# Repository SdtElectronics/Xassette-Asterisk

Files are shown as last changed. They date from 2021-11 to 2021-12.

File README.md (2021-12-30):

# Xassette-Asterisk
Evaluation board for AllWinner's RISC-V 64 SoC F133/D1s

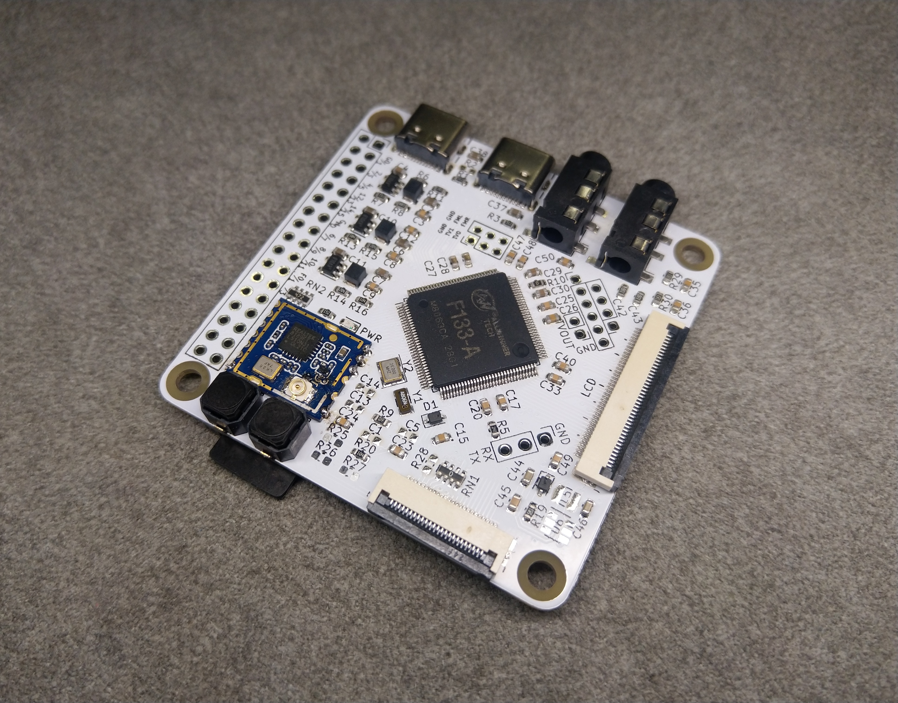
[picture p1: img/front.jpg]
front


## Highlights
* Breaks out all IOs, involving analog peripherals, in a compact 56*56mm 2-layer board
* Comes with standard interfaces including USB, micro SD, LCD, Line-in and headphone
* Optimized components arrangement for soldering on a hot plate

## About the Chip
D1s/F133: RISC-V 64 single core @1.008G with in package 64MB DDR2

## Guides
[Quick Start](docs/quickStart.md)

[Troubleshooting](docs/troubleshooting.md)

[Wi-Fi](docs/WiFi.md)

## Pin Out
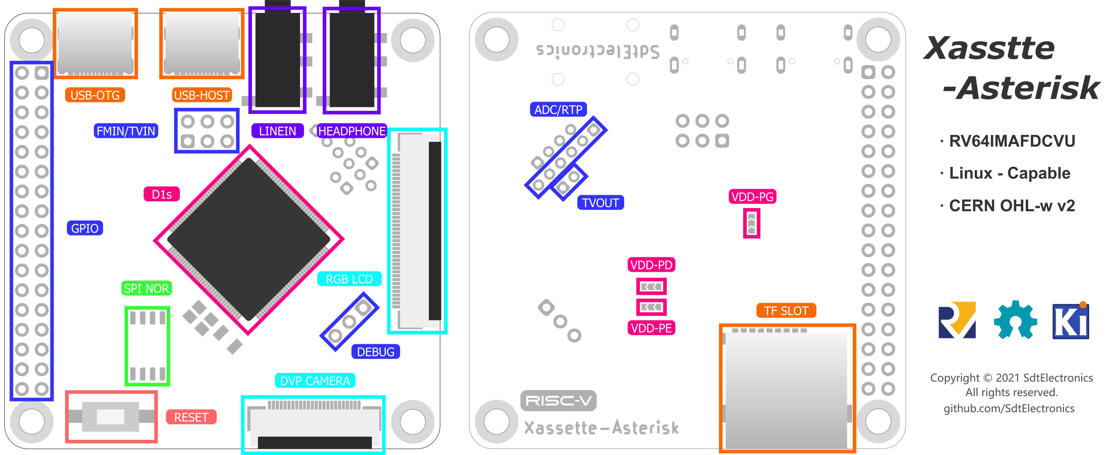
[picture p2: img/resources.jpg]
resources


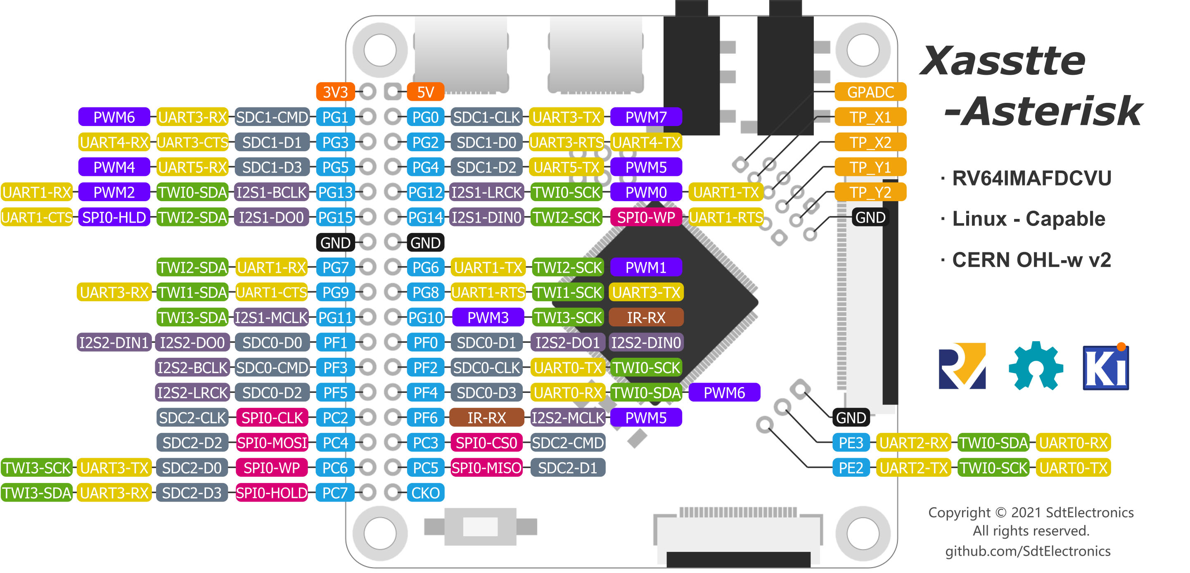
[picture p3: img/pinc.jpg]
pinout


Pins for LCD and DVP camera can also be used as IOs. See schematic below for detailed pin assignment.

## Schematic & BOM
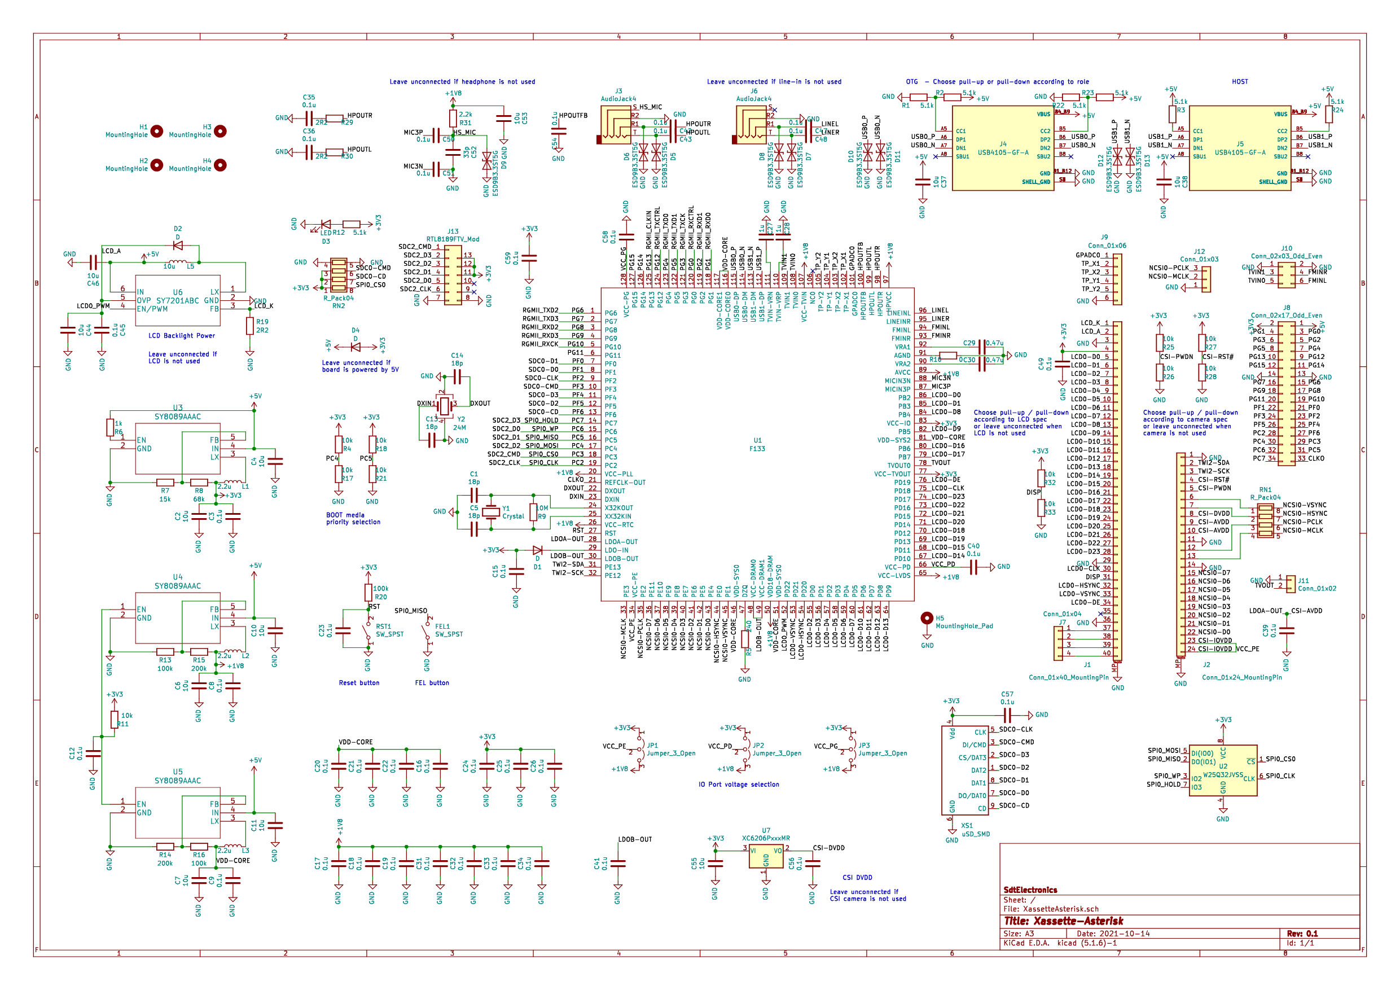
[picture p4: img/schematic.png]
schematic


The schematic in KiCAD format is available under [hw](hw/). BOM in csv format is at [docs/BOM.csv](docs/BOM.csv), and kitspace provides an [online BOM](https://kitspace.org/interactive_bom/?github.com/SdtElectronics/Xassette-Asterisk). Do note that many components are optional (required by some specific peripherals)!

## Notes
* Leave all BOOT selection resistors unconnected if only one BOOT media is present
* Choose load capacitors according to specs of crystals
* When board is to be powered by 3.3V, connect to the power via the 3.3V pin of the pinheader, and `D4` should be soldered. Note USB host will not work properly in this condition due to the absence of 5V power.

## Accessories
### IO Expansion Board
To make use of IOs in the LCD port easier, [this expansion board](hw/auxiliary/Brk40p) converts all nets from FPC to 2.54mm pin headers with labeled IO indices. For 24pin DVP port, there is also an [expansion board](https://github.com/SdtElectronics/Biscuits/tree/master/24P_FPC_FFC_Breakout) but with no labels.

## CHANGELOG
### hw-v0.2 
* Added WiFi Module on `sdc2`, sharing pins with SPI Flash
* Added FEL button
* Added ESD protection on USB and audio jacks
* Changed pin headers of TVIN and FMIN (`J10`) to 2x3 2.00mm to optimize routing of USB

### fw-v0.2
* Enabled pins of `sdc2` for SDIO
* Packed driver for RTL8189ftv WiFi module

**NOTE**: hw-v0.1 board can **NOT** boot fw-v0.2 firmware. Use fw-v0.1 instead.

### hw-v0.3
* Fix pull-up/down resistors for USB-PD role detection
* Align voltage of `VDDIO` in DVP interface with `VCC-PE`

## FAQ
> Are you going to sell some manufactured boards?

No. I have no time and resource to batch manufacture this board. Some commercial boards should come in a couple of months (not from me).

> Where to buy some D1s chips?

There are several suppliers providing samples on taobao.

> Where to find the BSP? Can I build the firmware myself?

The tina BSP for D1s is opened to public and you can download it via [the mirror at linux-sunxi.org](https://dl.linux-sunxi.org/D1/SDK/). There is also [a good guide on linux-sunxi.org](https://linux-sunxi.org/D1_SDK_Howto) covering the building and trouble shooting.

> More information? Like what can this board do now?

The progress of this project is logged at [this Hackaday page](https://hackaday.io/project/182389-the-cheapest-risc-v-64-computer-by-now), and this repository will contain the source and documentation of this board only. Currently this board can boot up the tina Linux system (an OpenWRT fork by Allwinner) and populate a shell prompt via the serial, drive a parallel RGB display, play sounds via the headphone socket, and record audio from MIC. More functionalities will be tested in the future.

**Additional Words**

This project has gained unexpected popularity since the announcement. Thanks for all the interest! However, I am merely an enthusiast with limited time can be put on this, so I am sorry to disappoint who want to buy one. It is perfectly Okay if someone want to put this into production, as long as my work is acknowledged and the Licence is followed (better if you could contact me in advance). 

D1s is an awesome chip with many features to be exploited. Designing a PCB is not hard as the arrangement of pins is quite thoughtful. The crucial part is correct values of some key components, and they were all marked in the schematic. A symbol of D1s with annotated pins is also included in this repository, so this should also be a good start point for your own design.

## External Links
[Page on Hackaday ](https://hackaday.io/project/182389-the-cheapest-risc-v-64-computer-by-now)

[Post about batch manufacturing by cnx-software](https://www.cnx-software.com/2021/12/24/manufacturing-xassette-asterisk-open-source-hardware-board/)

[WiKi on Linux-sunxi.org](https://linux-sunxi.org/Xassette_Asterisk)

## Licence
This project is available under the [CERN OHL-w v2](https://ohwr.org/project/cernohl/wikis/Documents/CERN-OHL-version-2) licence.

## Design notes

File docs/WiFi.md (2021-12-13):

# WiFi
Xassette-Asterisk supports SDIO Wi-Fi module since hw v0.2. The module is connected to SoC via `sdc2` which shares pins with SPI flash, thus the flash won't be available when Wi-Fi module is in use.

## Module Selection
Due to the limited area of PCB, there is no onboard antenna for the module. Thus the module must have an IPEX socket to connect external antenna. RTL8189ftv is the module used to test the Wi-Fi functionality, and it will be the example for the following sections.

## Kernel Configuration
To enable the `sdc2` interface as SDIO card controller, the board device tree must configure `sdc2` as below:
```c
&sdc2 {
        non-removable;
        bus-width = <4>;
        no-mmc;
        no-sd;
        cap-sd-highspeed;
        cap-sdio-irq;
        keep-power-in-suspend;
        ignore-pm-notify;
        max-frequency = <150000000>;
        ctl-spec-caps = <0x308>;
        status = "okay";
};
```
and the `no-sdio` property must be removed from the `sdc2` node in chip's device tree (sun20iw1p1.dtsi).

After this, the SD card will probably be probed as `mmcblk1` (originally `mmcblk0`) and causes the VFS fail to mount the root partition. Changing the path of root (in bootargs) in u-boot solves the problem.

The firmware image with configuration supports Wi-Fi is available in [release](https://github.com/SdtElectronics/Xassette-Asterisk/releases/tag/fw-v0.2). It can be flashed to the card following [Quick Start](docs/quickStart.md).

## Driver
Driver for RTL8189ftv can be compiled following [sunxi WiKi](https://linux-sunxi.org/Wifi#RTL8189FTV). This driver is included in the firmware mentioned above. Load it with 
```
insmod 8189fs
```
and the module is ready to work.

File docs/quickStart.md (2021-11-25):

# Quick Start
## Burn Tina Firmware
Get the firmware in [releases](https://github.com/SdtElectronics/Xassette-Asterisk/releases/tag/fw-v0.1-beta). Extract the tarball and you will get a card image. It could be burned to a SD using `dd` command:
```bash
dd if=fw.bin of=${card} bs=512
```
where ${card} is the path to the device file (under `/dev/`) to your card.

## Access The Shell via ADB
The firmware is preconfigured so that it works as an ADB USB gadget after booted up. Connect the board via the otg port and if your computer has installed ADB and corresponding drivers, the shell should be prompted after entering
```bash
adb shell
```

## Debugging via Serial
The serial prints boot log and kernel messages in addition to the shell prompt. The default debug serial is `UART0` at `PE3` and `PE2`. It can be easily connected with a pinheader at the bottom right of the board.

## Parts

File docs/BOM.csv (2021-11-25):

Comment | Designator | Footprint | Pins | Quantity
1u | C28,C27, | C_0603_1608Metric | 2 | 2
0.47u | C29,C30, | C_0603_1608Metric | 2 | 2
10u | C44,C38,C37,C4,C2,C6,C7,C10,C11, | C_0603_1608Metric | 2 | 9
0.1u | C50,C49,C48,C47,C46,C45,C43,C42,C40,C36,C35,C33,C17,C26,C25,C24,C1,C5,C23,C20,C3,C12,C9,C8,C15, | C_0603_1608Metric | 2 | 27
1N5819 | D1,D2, | D_SOD-323 | 2 | 2
LED | D3, | LED_0603_1608Metric | 2 | 1
Conn_01x40_MountingPin | J1, | TE_4-1734839-0_1x40-1MP_P0.5mm_Horizontal | 42 | 1
Conn_01x24_MountingPin | J2, | TE_2-1734839-4_1x24-1MP_P0.5mm_Horizontal | 26 | 1
2.2u | L2,L3,L1, | L_Wuerth_MAPI-2510 | 2 | 3
10u | L5, | L_Wuerth_MAPI-2510 | 2 | 1
0 | R10, | R_0603_1608Metric | 2 | 1
100k | R13,R11,R12,R16, | R_0603_1608Metric | 2 | 4
200k | R15,R14, | R_0603_1608Metric | 2 | 2
1.5k | R24,R3,R1, | R_0603_1608Metric | 2 | 4
2R2 | R30,R29,R19, | R_0603_1608Metric | 2 | 3
10k | R34,R23,R22, | R_0603_1608Metric | 2 | 11
240 | R5, | R_0603_1608Metric | 2 | 1
15k | R7, | R_0603_1608Metric | 2 | 1
68k | R8, | R_0603_1608Metric | 2 | 1
1k | R6,R20, | R_0603_1608Metric | 2 | 3
0 | RN1, | R_Array_Convex_4x0603 | 8 | 1
SW_SPST | RST, | SW_SPST_FSMSM | 2 | 1
F133 | U1, | LQFP-128_14x14mm_P0.4mm | 128 | 1
W25Q32JVSS | U2, | SOIC-8_5.23x5.23mm_P1.27mm | 8 | 1
SY8089AAAC | U4,U3,U5, | SOT-23-5 | 5 | 3
SY7201ABC | U6, | SOT-23-6 | 6 | 1
32.768k | Y1, | Crystal_SMD_3215-2Pin_3.2x1.5mm | 2 | 1
24M | Y2, | Crystal_SMD_3225-4Pin_3.2x2.5mm | 4 | 1
33p | C52, | C_0603_1608Metric | 2 | 1
10u | C53, | C_0603_1608Metric | 2 | 2
0.1u | C58,C57,C54,C51,C41,C39,C34,C32,C31,C19,C18,C16,C21,C22, | C_0603_1608Metric | 2 | 15
2.2k | R31, | R_0603_1608Metric | 2 | 1
10k | R32, | R_0603_1608Metric | 2 | 2
Through Hole Items
Conn_02x03_Odd_Even | J10, | PinHeader_2x03_P2.54mm_Vertical | 6 | 1
Conn_01x02 | J11, | PinHeader_1x02_P2.00mm_Vertical | 2 | 1
Conn_01x03 | J12, | PinHeader_1x03_P2.54mm_Vertical | 3 | 1
PJ320D | J3,J6, | Jack_3.5mm_PJ320D_Horizontal | 6 | 2
USB4105-GF-A | J5,J4, | GCT_USB4105-GF-A | 18 | 2
Conn_01x04 | J7, | PinSocket_1x04_P2.00mm_Vertical | 4 | 1
Conn_02x17_Odd_Even | J8, | PinSocket_2x17_P2.54mm_Vertical | 34 | 1
Conn_01x06 | J9, | PinHeader_1x06_P2.00mm_Vertical | 6 | 1
uSD_SMD | XS1, | Conn_uSDcard | 15 | 1

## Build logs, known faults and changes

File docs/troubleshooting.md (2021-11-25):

# Troubleshooting

## General
Check voltages of each group of power. The typical voltages for power nets are:
- `3V3`: 3.3V
- `1V8`: 1.8V
- `VDD-CORE`: 0.9V
- `LDOB-OUT`: 1.2-1.3V in FEL mode, 1.8V in normal operation

Check whether there are bad electrical connections.

Check whether separate nets are accidently connected.

## Nothing Is Printed to Serial
Check whether TX and RX signals are matched. Try interchanging them. Remove the boot media and connect the board to a computer via the otg port. If a new device is detected by the computer, it means the chip worked properly and you should check the boot media. Otherwise use an oscilloscope to check whether the crystal is oscillating. If not, check the power, and in worst cases the chip is probably dead.

## System Frequently Hangs or Reboot
Use a better power supply. Remove the load capacitors of 24M crystal (`C13`, `C14`). If the problem is eliminated it indicates the value of load capacitors was too large.

## MMC Errors or Reboot after Mounting New Partion
Check the soldering of the card slot. Use a better card as bad blocks can cause failure.

## LCD Is Not Working
If the backlight is not up, check the boost circuit. Otherwise check the level of `DISP` signal. It should be pulled high for most panels i.e. `R32` should be soldered.

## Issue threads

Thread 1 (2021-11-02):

Any plans for manufacturing?

VedantParanjape, 2021-11-02:
I and few of us would like to do a group buy, do you have a manufacturing plan or any pre made boards with you ?

We are discussing about it here, please join in if possible: https://discord.gg/g2QrdxpZ

cnxsoft, 2021-11-10:
I'm trying to get NextPCB to manufacture 10 fully assembled samples.
They have some questions about specific components, notably where to purchase components, and ask the exact part number for others.
[T-9pcs-BOM(1)-Component question confirm.xlsx](https://github.com/SdtElectronics/Xassette-Asterisk/files/7512594/T-9pcs-BOM.1.-Component.question.confirm.xlsx)

Could you help? Thanks in advance.

SdtElectronics, 2021-11-11:
> I'm trying to get NextPCB to manufacture 10 fully assembled samples. They have some questions about specific components, notably where to purchase components, and ask the exact part number for others. [T-9pcs-BOM(1)-Component question confirm.xlsx](https://github.com/SdtElectronics/Xassette-Asterisk/files/7512594/T-9pcs-BOM.1.-Component.question.confirm.xlsx)
>
> Could you help? Thanks in advance.

@cnxsoft
I have mentioned in the [README](https://github.com/SdtElectronics/Xassette-Asterisk/blob/master/README.md#schematic--bom) that quite a lot of components are optional. I won't recommend soldering them on a prototype, e.g. the nor flash and DVP camera related components (R25-28, C55, C56, C39), as they depend on the application (nor flash for example, you typically want a 64Mbit w25q64 for a minimal useful Linux image, but a 128Mbit w25q128 gives more space for more complex applications).  And note that some components **should NOT** be soldered together since they are mutual exclusive as Boolean switchs (e.g. R4, R18, R17, R21).

For through hole components, mainly pin headers here, I would suggest don't bother leaving them to the manufacturer, as some of them are not needed (for a prototype), and they can be hand soldered easily if you want them.

I have corrected some items in the BOM in this attachment and added some comments. However, problem can still occur as it is not me who contact the manufacturer directly. You may want to show me the rendered visual of SMT board from the manufacturer for further verification.
[T-9pcs-BOM.1.-Component.revised.xlsx](https://github.com/SdtElectronics/Xassette-Asterisk/files/7519220/T-9pcs-BOM.1.-Component.revised.xlsx)

VedantParanjape, 2021-11-20:
> I'm trying to get NextPCB to manufacture 10 fully assembled samples. They have some questions about specific components, notably where to purchase components, and ask the exact part number for others. [T-9pcs-BOM(1)-Component question confirm.xlsx](https://github.com/SdtElectronics/Xassette-Asterisk/files/7512594/T-9pcs-BOM.1.-Component.question.confirm.xlsx)
>
> Could you help? Thanks in advance.

Hey, if you have some leftovers, I'd be happy to buy. Do let me know.

cnxsoft, 2021-11-20:
@VedantParanjape NextPCB will be manufacturing and assembling the boards next week. Maybe I'll get them in two weeks. I'm not sure I'll be able to bring them up though. We'll see.

dwillmore, 2021-11-20:
Good work, cnxsoft, I look forward to your article on them.

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

cnxsoft, 2021-11-22:
@SdtElectronics Sorry to bother you again. The Gerber files are ready but the manufacturer has some questions.

> Our engineer has made the Working gerber for your this order, also with PDF format, please kindly check and see if everything is ok?
>
> Also please check the picture 1, for the position by arrow indicated, it can not be made as solder mask bridge, so our engineer suggest that help you connect the pads together(whole opening), is ok for you?(check the Working gerber)

I don't see any obvious issues in the Gerber, and I don't understand the picture 1 question. If you could comment that would be good. The files are attached below. Thank you.

[nextpcb-gerber.zip](https://github.com/SdtElectronics/Xassette-Asterisk/files/7580142/nextpcb-gerber.zip)

SdtElectronics, 2021-11-22:
@cnxsoft
I assume gaps between pads at some positions are too small to make solder mask upon. As long as the manufacturer will take care of the soldering that would not be a problem, otherwise the absence of solder mask may cause difficulty to soldering (by hand).

cnxsoft, 2021-12-10:
They've manufactured the first sample. See photos.

[T-E41684AST1，GE14895-Sample board photos.zip](https://github.com/SdtElectronics/Xassette-Asterisk/files/7690936/T-E41684AST1.GE14895-Sample.board.photos.zip)

They are asking for feedback. It looks OK except they have not soldered all capacitors yet. What's strange is that they had to solder some of the components at an angle (First photos with red circles), but will fix it later. I don't see this problem on your board, was it an issue?

Their comment:
"In addition, the parts circled by red line, the pads are a little smaller, they may be pulled off in Reflow soldering process, we will help you repair them manually before shipment, but also please improve your this design in future."

SdtElectronics, 2021-12-11:
@cnxsoft
I did find some issues from the pics you uploaded. `R21`, `R18` and `R17`, `R14` are jumpers for boot media selection and they must **NOT** be soldered simultaneously. I have mentioned this in notes of README, as well as the commented BOM list. Should a card was used as the only boot media, all these 4 resistors can be removed. Same reason for `R33` and `R32`. They are jumpers and only one of them should be soldered (`R32` for most LCD panels).

About the skew components (3 inductors in your pics), I have also experienced this when soldering by hot plate (they were right, melted solder paste pulled components off) and I have to adjust them manually. This would not be a problem as long as two pads of the inductor are not shorted.

Closed 2021-11-02.

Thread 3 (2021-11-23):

Firmware image

suarezvictor, 2021-11-23:
Hi, I've got some of the chips and I plan to implement your board or a similar one.
Where to get the firmware images? Are them open source, at least partially?

SdtElectronics, 2021-11-24:
**TL;DR**
I will upload the full image of a bootable SD so it can be `dd`ed to the card directly, hopefully in a few days.

The tina SDK for D1 is open source and it can be get and built following [this instruction](https://d1.docs.aw-ol.com/study/study_4compile/). D1s and D1 has little difference on DRAM so the source should be patched according to [this post](https://bbs.aw-ol.com/topic/384/%E7%AE%80%E5%8D%95%E4%BF%AE%E6%94%B9-%E5%93%AA%E5%90%92d1-tina-sdk-%E7%9A%84-sys_config-fex-%E5%92%8C-board-dts-%E8%AE%A9d1s%E5%85%88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).  All these are in Chinese. You will probably encounter some error during build, and solutions on [aw-dl forum](https://bbs.aw-ol.com/) are in Chinese as well. After a successful compilation, the firmware still has little problem and I have to tune some configuration. I considered writing an instruction for building firmware manually but as you can see that would be very complicated. Thus for anyone who want to build manually, I would suggest you to wait for the mainline support. Before that you can use my image, which will be uploaded  soon. Currently I am working on some final testing.

suarezvictor, 2021-11-24:
Well this is a good start, thanks!
Mainlining could get a unknown amount of time, it seems using your instructions and image would be better. Hopefully you can share such instructions so developers like me can help on tweaking and improving it.

SdtElectronics, 2021-11-25:
The firmware is uploaded and it can be flashed following [Quick Start](https://github.com/SdtElectronics/Xassette-Asterisk/blob/master/docs/quickStart.md).

suarezvictor, 2021-11-25:
This is much appreciated, what a nice project!

Closed 2021-11-25.

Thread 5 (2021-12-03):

My board doesn't boot

foxnux, 2021-12-03:
Thank you for sharing your great work.
I made my F133-A board based on your schematics but it doesn't boot.
There is no serial console data from the UART TX pin (PE2). I set 115200N81 on minicom.
I flashed your prebuilt test image on a micro SD card for my hardware bring up.

I checked power rails and 24Mhz/32.768Khz oscillators work fine.
3.3V: 3.328V
1.8V: 1.813V
Core: 0.908V
LDO_B: 1.379V (!)

When I connected the USB Port 0 to my Linux PC, I could see "ID 1f3a:efe8" from lsusb output.
It seemed that the FEL mode worked at least.

I've checked the SD interface CLK and CMD lines with an oscilloscope. But they were always low (zero volt).
I think BROM didn't try fetching any boot data from the SD card.
I didn't connect any resistors to the boot mode select pins (MOSI/MISO).

Can you please tell me what I am missing?

Thanks in advance,

SdtElectronics, 2021-12-03:
It is probably normal if LDO_B is at 1.3V in FEL mode. There should be no output from the serial in FEL mode and I see no problem from the rest of your description. Have you soldered the jumping wires for voltage selection? Have you tried with another card? You can also try solder the card slot again to ensure it is connected properly.

foxnux, 2021-12-06:
Thank you for the valuable feedback.
I've checked VCC-PD, VCC-PE, VCC-PG and VCC-IO pins. All of them shows stable 3.32Volt
I tried a couple of different micro SD cards. There is no signal toggling on the SD card CLK signal yet. :(
I will check my SD card schematics more carefully.

foxnux, 2021-12-06:
Really appreciate your insight.
After replacing the SD card slot with a different one, I could see the following boot message from the serial console finally. :)

`[217]HELLO! BOOT0 is starting!
[220]BOOT0 commit : 27369ab
[223]set pll start
[225]periph0 has been enabled
[228]set pll end
[229][pmu]: bus read error
[232]board init ok
[234]ZQ value = 0x31***********
[237]get_pmu_exist() = -1
[239]ddr_efuse_type: 0xa
[242][AUTO DEBUG] single rank and full DQ!
[246]ddr_efuse_type: 0xa
[249][AUTO DEBUG] rank 0 row = 13
[252][AUTO DEBUG] rank 0 bank = 4
[255][AUTO DEBUG] rank 0 page size = 2 KB
[259]DRAM BOOT DRIVE INFO: V0.24
[262]DRAM CLK = 528 MHz
[264]DRAM Type = 2 (2:DDR2,3:DDR3)
[268]DRAMC read ODT  off.
[270]DRAM ODT off.
[272]ddr_efuse_type: 0xa
[275]DRAM SIZE =64 M
[278]DRAM simple test OK.
[281]dram size =64
[283]card no is 0
[284]sdcard 0 line count 4
[287][mmc]: mmc driver ver 2021-04-2 16:45
[296][mmc]: Wrong media type 0x0
[299][mmc]: ***Try SD card 0***
[312][mmc]: HSSDR52/SDR25 4 bit
[315][mmc]: 50000000 Hz
[317][mmc]: 60906 MB
[319][mmc]: ***SD/MMC 0 init OK!!!***
[366]Loading boot-pkg Succeed(index=0).
[370]Entry_name        = opensbi
[373]Entry_name        = u-boot
[377]Entry_name        = dtb
[380]mmc not para
[381]Jump to second Boot.

OpenSBI v0.6
   ____                    _____ ____ _____
  / __ \                  / ____|  _ \_   _|
 | |  | |_ __   ___ _ __ | (___ | |_) || |
 | |  | | '_ \ / _ \ '_ \ \___ \|  _ < | |
 | |__| | |_) |  __/ | | |____) | |_) || |_
  \____/| .__/ \___|_| |_|_____/|____/_____|
        | |
        |_|

Platform Name          : T-HEAD Xuantie Platform
Platform HART Features : RV64ACDFIMSUVX
Platform Max HARTs     : 1
Current Hart           : 0
Firmware Base          : 0x40000400
Firmware Size          : 75 KB
Runtime SBI Version    : 0.2

MIDELEG : 0x0000000000000222
MEDELEG : 0x000000000000b1ff
PMP0    : 0x0000000040000000-0x000000004001ffff (A)
PMP1    : 0x0000000040000000-0x000000007fffffff (A,R,W,X)
PMP2    : 0x0000000080000000-0x00000000bfffffff (A,R,W,X)
PMP3    : 0x0000000000020000-0x0000000000027fff (A,�

U-Boot 2018.05-g0a88ac9 (Apr 30 2021 - 11:23:28 +0000) Allwinner Technology

[00.464]DRAM:  64 MiB
[00.466]Relocation Offset is: 01ef0000
[00.471]secure enable bit: 0
[00.473]CPU=1008 MHz,PLL6=600 Mhz,AHB=200 Mhz, APB1=100Mhz  MBus=300Mhz
[00.480]flash init start
[00.482]workmode = 0,storage type = 1
[00.485][mmc]: mmc driver ver uboot2018:2021-04-16 14:23:00-1
[00.491][mmc]: get sdc_type fail and use default host:tm1.
[00.497][mmc]: can't find node "mmc0",will add new node
[00.502][mmc]: fdt err returned <no error>
[00.506][mmc]: Using default timing para
[00.509][mmc]: SUNXI SDMMC Controller Version:0x50310
[00.528][mmc]: card_caps:0x3000000a
[00.531][mmc]: host_caps:0x3000003f
[00.536]sunxi flash init ok
[00.538]line:714 init_clocks
__clk_init: clk pll_periph0x2 already initialized
register fix_factor clk error
[00.549]drv_disp_init
fdt_getprop_u32 s_pwm.pwm-base fail
[00.564]drv_disp_init finish
[00.567]boot_gui_init:start
[00.570]set disp.dev2_output_type fail. using defval=0
[00.576]boot_gui_init:finish
partno erro : can't find partition bootloader
54 bytes read in 1 ms (52.7 KiB/s)
[00.596]bmp_name=bootlogo.bmp size 307254
307254 bytes read in 15 ms (19.5 MiB/s)
[00.631]Loading Environment from SUNXI_FLASH... OK
[00.650]out of usb burn from boot: not need burn key
root_partition is rootfs
set root to /dev/mmcblk0p5
[00.660]update part info
[00.663]update bootcmd
[00.666]change working_fdt 0x42aafda8 to 0x42a8fda8
[00.687]update dts
Hit any key to stop autoboot:  0
[00.756]LCD open finish
Android's image name: d1-f133evb1_rgb8
No reserved memory region found in source FDT
[01.111]
Starting kernel ...

[01.114][mmc]: MMC Device 2 not found
[01.117][mmc]: mmc 2 not find, so not exit
[    0.000000] OF: fdt: Ignoring memory range 0x40000000 - 0x40200000
[    0.000000] Linux version 5.4.61 (gcast@PowerEdge-T640) (riscv64-unknown-linux-gnu-gcc (C-SKY RISCV Tools V1.8.4 B20200702) 8.1.0, GNU ld (GNU Binutils) 2.32) #1 PR1
[    0.000000] cma: Reserved 8 MiB at 0x0000000043800000
[    0.000000] Zone ranges:
[    0.000000]   DMA32    [mem 0x0000000040200000-0x0000000043ffffff]
[    0.000000]   Normal   empty
[    0.000000] Movable zone start for each node
[    0.000000] Early memory node ranges
[    0.000000]   node   0: [mem 0x0000000040200000-0x0000000043ffffff]
[    0.000000] Initmem setup node 0 [mem 0x0000000040200000-0x0000000043ffffff]
[    0.000000] On node 0 totalpages: 15872
[    0.000000]   DMA32 zone: 217 pages used for memmap
[    0.000000]   DMA32 zone: 0 pages reserved
[    0.000000]   DMA32 zone: 15872 pages, LIFO batch:3
[    0.000000] elf_hwcap is 0x20112d
[    0.000000] pcpu-alloc: s0 r0 d32768 u32768 alloc=1*32768
[    0.000000] pcpu-alloc: [0] 0
[    0.000000] Built 1 zonelists, mobility grouping on.  Total pages: 15655
[    0.000000] Kernel command line: earlyprintk=sunxi-uart,0x02500000 clk_ignore_unused initcall_debug=0 console=ttyS0,115200 loglevel=8 root=/dev/mmcblk0p5 init=/sbinr
[    0.000000] Dentry cache hash table entries: 8192 (order: 4, 65536 bytes, linear)
[    0.000000] Inode-cache hash table entries: 4096 (order: 3, 32768 bytes, linear)
[    0.000000] Sorting __ex_table...
[    0.000000] mem auto-init: stack:off, heap alloc:off, heap free:off
[    0.000000] Memory: 42204K/63488K available (6080K kernel code, 663K rwdata, 2097K rodata, 192K init, 254K bss, 13092K reserved, 8192K cma-reserved)
[    0.000000] SLUB: HWalign=64, Order=0-3, MinObjects=0, CPUs=1, Nodes=1
[    0.000000] rcu: Preemptible hierarchical RCU implementation.
[    0.000000]  Tasks RCU enabled.
[    0.000000] rcu: RCU calculated value of scheduler-enlistment delay is 10 jiffies.
[    0.000000] NR_IRQS: 0, nr_irqs: 0, preallocated irqs: 0
[    0.000000] plic: mapped 200 interrupts with 1 handlers for 2 contexts.
[    0.000000] riscv_timer_init_dt: Registering clocksource cpuid [0] hartid [0]
[    0.000000] clocksource: riscv_clocksource: mask: 0xffffffffffffffff max_cycles: 0x588fe9dc0, max_idle_ns: 440795202592 ns
[    0.000006] sched_clock: 64 bits at 24MHz, resolution 41ns, wraps every 4398046511097ns
[    0.000027] riscv_timer_clockevent depends on broadcast, but no broadcast function available
[    0.000377] clocksource: timer: mask: 0xffffffff max_cycles: 0xffffffff, max_idle_ns: 79635851949 ns
[    0.001030] Console: colour dummy device 80x25
[    0.001077] Calibrating delay loop (skipped), value calculated using timer frequency.. 48.00 BogoMIPS (lpj=240000)
[    0.001096] pid_max: default: 32768 minimum: 301
[    0.001314] Mount-cache hash table entries: 512 (order: 0, 4096 bytes, linear)
[    0.001333] Mountpoint-cache hash table entries: 512 (order: 0, 4096 bytes, linear)
[    0.003414] ASID allocator initialised with 65536 entries
[    0.003618] rcu: Hierarchical SRCU implementation.
[    0.004364] devtmpfs: initialized
[    0.017852] random: get_random_u32 called from bucket_table_alloc.isra.31+0x4e/0x15e with crng_init=0
[    0.018883] clocksource: jiffies: mask: 0xffffffff max_cycles: 0xffffffff, max_idle_ns: 19112604462750000 ns
[    0.018916] futex hash table entries: 256 (order: 0, 6144 bytes, linear)
[    0.019495] pinctrl core: initialized pinctrl subsystem
[    0.021126] NET: Registered protocol family 16
[    0.023254] DMA: preallocated 256 KiB pool for atomic allocations
[    0.023988] cpuidle: using governor menu
[    0.068128] rtc_ccu: sunxi ccu init OK
[    0.076176] clock: sunxi ccu init OK
[    0.077230] clock: sunxi ccu init OK
[    0.115760] iommu: Default domain type: Translated
[    0.115964] sunxi iommu: irq = 4
[    0.117251] SCSI subsystem initialized
[    0.117647] usbcore: registered new interface driver usbfs
[    0.117742] usbcore: registered new interface driver hub
[    0.117861] usbcore: registered new device driver usb
[    0.118087] mc: Linux media interface: v0.10
[    0.118157] videodev: Linux video capture interface: v2.00
[    0.119431] sunxi-msgbox-amp 3003000.msgbox: invalid resource
[    0.120241] Advanced Linux Sound Architecture Driver Initialized.
[    0.121057] Bluetooth: Core ver 2.22
[    0.121152] NET: Registered protocol family 31
[    0.121163] Bluetooth: HCI device and connection manager initialized
[    0.121190] Bluetooth: HCI socket layer initialized
[    0.121211] Bluetooth: L2CAP socket layer initialized
[    0.121256] Bluetooth: SCO socket layer initialized
[    0.121588] pwm module init!
[    0.123291] g2d 5410000.g2d: Adding to iommu group 0
[    0.123875] G2D: rcq version initialized.major:250
[    0.125432] clocksource: Switched to clocksource riscv_clocksource
[    0.139702] sun8iw20-pinctrl 2000000.pinctrl: initialized sunXi PIO driver
[    0.159088] thermal_sys: Registered thermal governor 'step_wise'
[    0.159095] thermal_sys: Registered thermal governor 'user_space'
[    0.159705] NET: Registered protocol family 2
[    0.160622] tcp_listen_portaddr_hash hash table entries: 256 (order: 0, 4096 bytes, linear)
[    0.160673] TCP established hash table entries: 512 (order: 0, 4096 bytes, linear)
[    0.160692] TCP bind hash table entries: 512 (order: 0, 4096 bytes, linear)
[    0.160708] TCP: Hash tables configured (established 512 bind 512)
[    0.160887] UDP hash table entries: 256 (order: 1, 8192 bytes, linear)
[    0.160938] UDP-Lite hash table entries: 256 (order: 1, 8192 bytes, linear)
[    0.161223] NET: Registered protocol family 1
[    0.164084] Initialise system trusted keyrings
[    0.164411] workingset: timestamp_bits=62 max_order=14 bucket_order=0
[    0.172325] squashfs: version 4.0 (2009/01/31) Phillip Lougher
[    0.193403] Key type asymmetric registered
[    0.193420] Asymmetric key parser 'x509' registered
[    0.193448] io scheduler mq-deadline registered
[    0.193458] io scheduler kyber registered
[    0.193482] atomic64_test: passed
[    0.194878] [DISP]disp_module_init
[    0.195632] disp 5000000.disp: Adding to iommu group 0
[    0.196310] [DISP] disp_init,line:2385:
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
foxnux, 2021-12-06:
Excuse me. It's me again.
After changing the SD card detection signal(PF6:SDC0_CD) polarity, it booted fine.
My SD card connector has an opposite detection switch unexpectedly.

Again, really appreciate your amazing open source hardware project !
I couldn't image I was able to build & boot a Linux SBC in a couple of weeks.

Closed 2021-12-06.

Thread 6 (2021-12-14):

是否可以 apt

gonboy, 2021-12-14:

SdtElectronics, 2021-12-14:
Short answer: You **can't** use APT with the firmware I uploaded.

Tina Linux, which is the distro in the uploaded firmware, is an openWRT fork by Allwinner. Package management system for Debian family is not available, but opkg is included in the firmware.

However, I had modified [a script to generate Debian rootfs for riscv64 architecture](https://github.com/SdtElectronics/debian-rootfs). You can `chroot` into the generated rootfs and use package management utilities for Debian.

Closed 2021-12-14.

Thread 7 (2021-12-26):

Use SDIO3 for Wifi to avoid the sharing pin with SPI?

tonyho, 2021-12-26:
Since D1s has 3 SDIO, can we use SDIO3 for wifi ?
In such case, we can boot the D1s from SPI nand.

SdtElectronics, 2021-12-28:
Yeah, D1s has 3 SDIOs, and they were labeled as SMHC0, SMHC1 and SMHC2 in the chip manual, and `sdc0`,  `sdc1`, `sdc2` in the device tree. To avoid ambiguity, I use the device tree notation here (and in README).

WiFi module is connected to `sdc2` on Xasstte-Asterisk, but it can also be connected to `sdc1`, and this is what supposed to be (`sdc0` for mmc card, `sdc1` for WiFi, `sdc2` for bootable emmc or multiplex as SPI for flash). Sadly, when designing the first version, supporting WiFi wasn't put into consideration, thus there is no space on board for a module connecting to `sdc1`. However, if you don't mind connecting an external board via the pin header, or change the board format and draw your own, it is possible (and preferable) to use `sdc1` for WiFi. Note that the firmware in this repository won't support this configuration, and you have to edit the device tree in source and compile your own firmware.

Closed 2021-12-28.

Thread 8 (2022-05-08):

Still can't forget the LAN/Net external module board, what is the status now?

tonyho, 2022-05-08:
Any further info about the external LAN HW module?

dwillmore, 2023-02-23:
I have some LAN8720 boards coming and I'm going to see if I can get one to work with my board.  I haven't looked to see which connector the I/O is on.  I hope it's on the pin header or this will be a lot more work.

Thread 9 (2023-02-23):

First boot of new board failed

dwillmore, 2023-02-23:
Hello!  I got one of the boards that cnx-soft made a while back.  I'm sorry it sat on my to-do list for so long.  Jean-Luc had problems sourcing some of the caps so my board needed some soldering done before it was useable and I'm not all that fond of such tiny SMD work, so it's taken me a long time to get it done.  But I finished it today!  We had to sub in caps for the XTAL loading caps, but they should be good enough.  I was *one* 0.1uF cap short and I chose not to populate the cap across the reset switch.  I think I chose poorly because it seems that cap also helps time the initial reset signal.  Pressing the button resets it, so that's fine.

The problem is that the board won't load Linux.  Here's the capture of the boot process:
[D1S_1.txt](https://github.com/SdtElectronics/Xassette-Asterisk/files/10809610/D1S_1.txt)

OpenSBI loads and finds the SD card, but it doesn't seem to like what it finds.  FWIW, voltages look good, the board runs cool.  I will try other uSD cards just in case it doesn't like this one.  Thank you!

dwillmore, 2023-02-23:
I reflashed the (same) card with fw 0.2 and got the same result.  I then tried it on an old 8GB card and got the following failure:
[D1S_3.txt](https://github.com/SdtElectronics/Xassette-Asterisk/files/10809662/D1S_3.txt)

Advice on how proceed is welcomed.

dwillmore, 2023-02-23:
Logs were captured with a USB to serial dongle set to 3.3V and connected to the debug header.

SdtElectronics, 2023-02-23:
The log you uploaded shows that the board successfully booted into uboot. If it went to that stage the hardware probably has no problem. How did you flash the firmware to the card? Also, if the board you have is the version without WiFi, fw0.1 should be used.

dwillmore, 2023-02-23:
Thank you for your reply!  I use dd to write the fw image to the card "dd if=fw.img of=/dev/sdb bs=512 status=progress"  I then did a sync and ran "eject /dev/sdb" to make sure all data was written.

I tried with the fw0.1 and got this result:
[D1S_5.txt](https://github.com/SdtElectronics/Xassette-Asterisk/files/10809858/D1S_5.txt)

dwillmore, 2023-02-24:
It really appears like the firmware image is incorrect.  I tried to look at it with fdisk and it looks like a 2T GPT partitioned disc--which seems very wrong.  The errors show it saying that the partition ends somewhere just before 32 GiB which is larger than the first card I tried which was 32GB.  It's much clearer with the 8GB card in it now.

How can this image work for others when it appears to be corrupted?

dwillmore, 2023-03-01:
Any advice on how I should proceed to debug this issue?

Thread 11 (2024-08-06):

Power sequencing is seemingly incorrect.

gibsonpil, 2024-08-06:
Correct me if I'm wrong, but it looks as though VCC-IO and VDD-SYS/VDD-CORE come up at the same time in your design. The datasheet for the F133/D1s states that the VCC-IO rail has to come up at least 2ms before VDD-SYS/VDD-CORE.

It seems as though you may have realized this and added an RC circuit to the enable pins on the buck converters for the +1.8V and +0.9V rails to delay start-up, but in actuality you should only delay enabling the +0.9V rail to achieve the desired sequencing.

Similarly, it looks like the reset pin is required to be held low until at least 64ms after VDD-CORE comes up, but in your design it's always pulled high (unless someone hits the reset button).

Let me know what you think.

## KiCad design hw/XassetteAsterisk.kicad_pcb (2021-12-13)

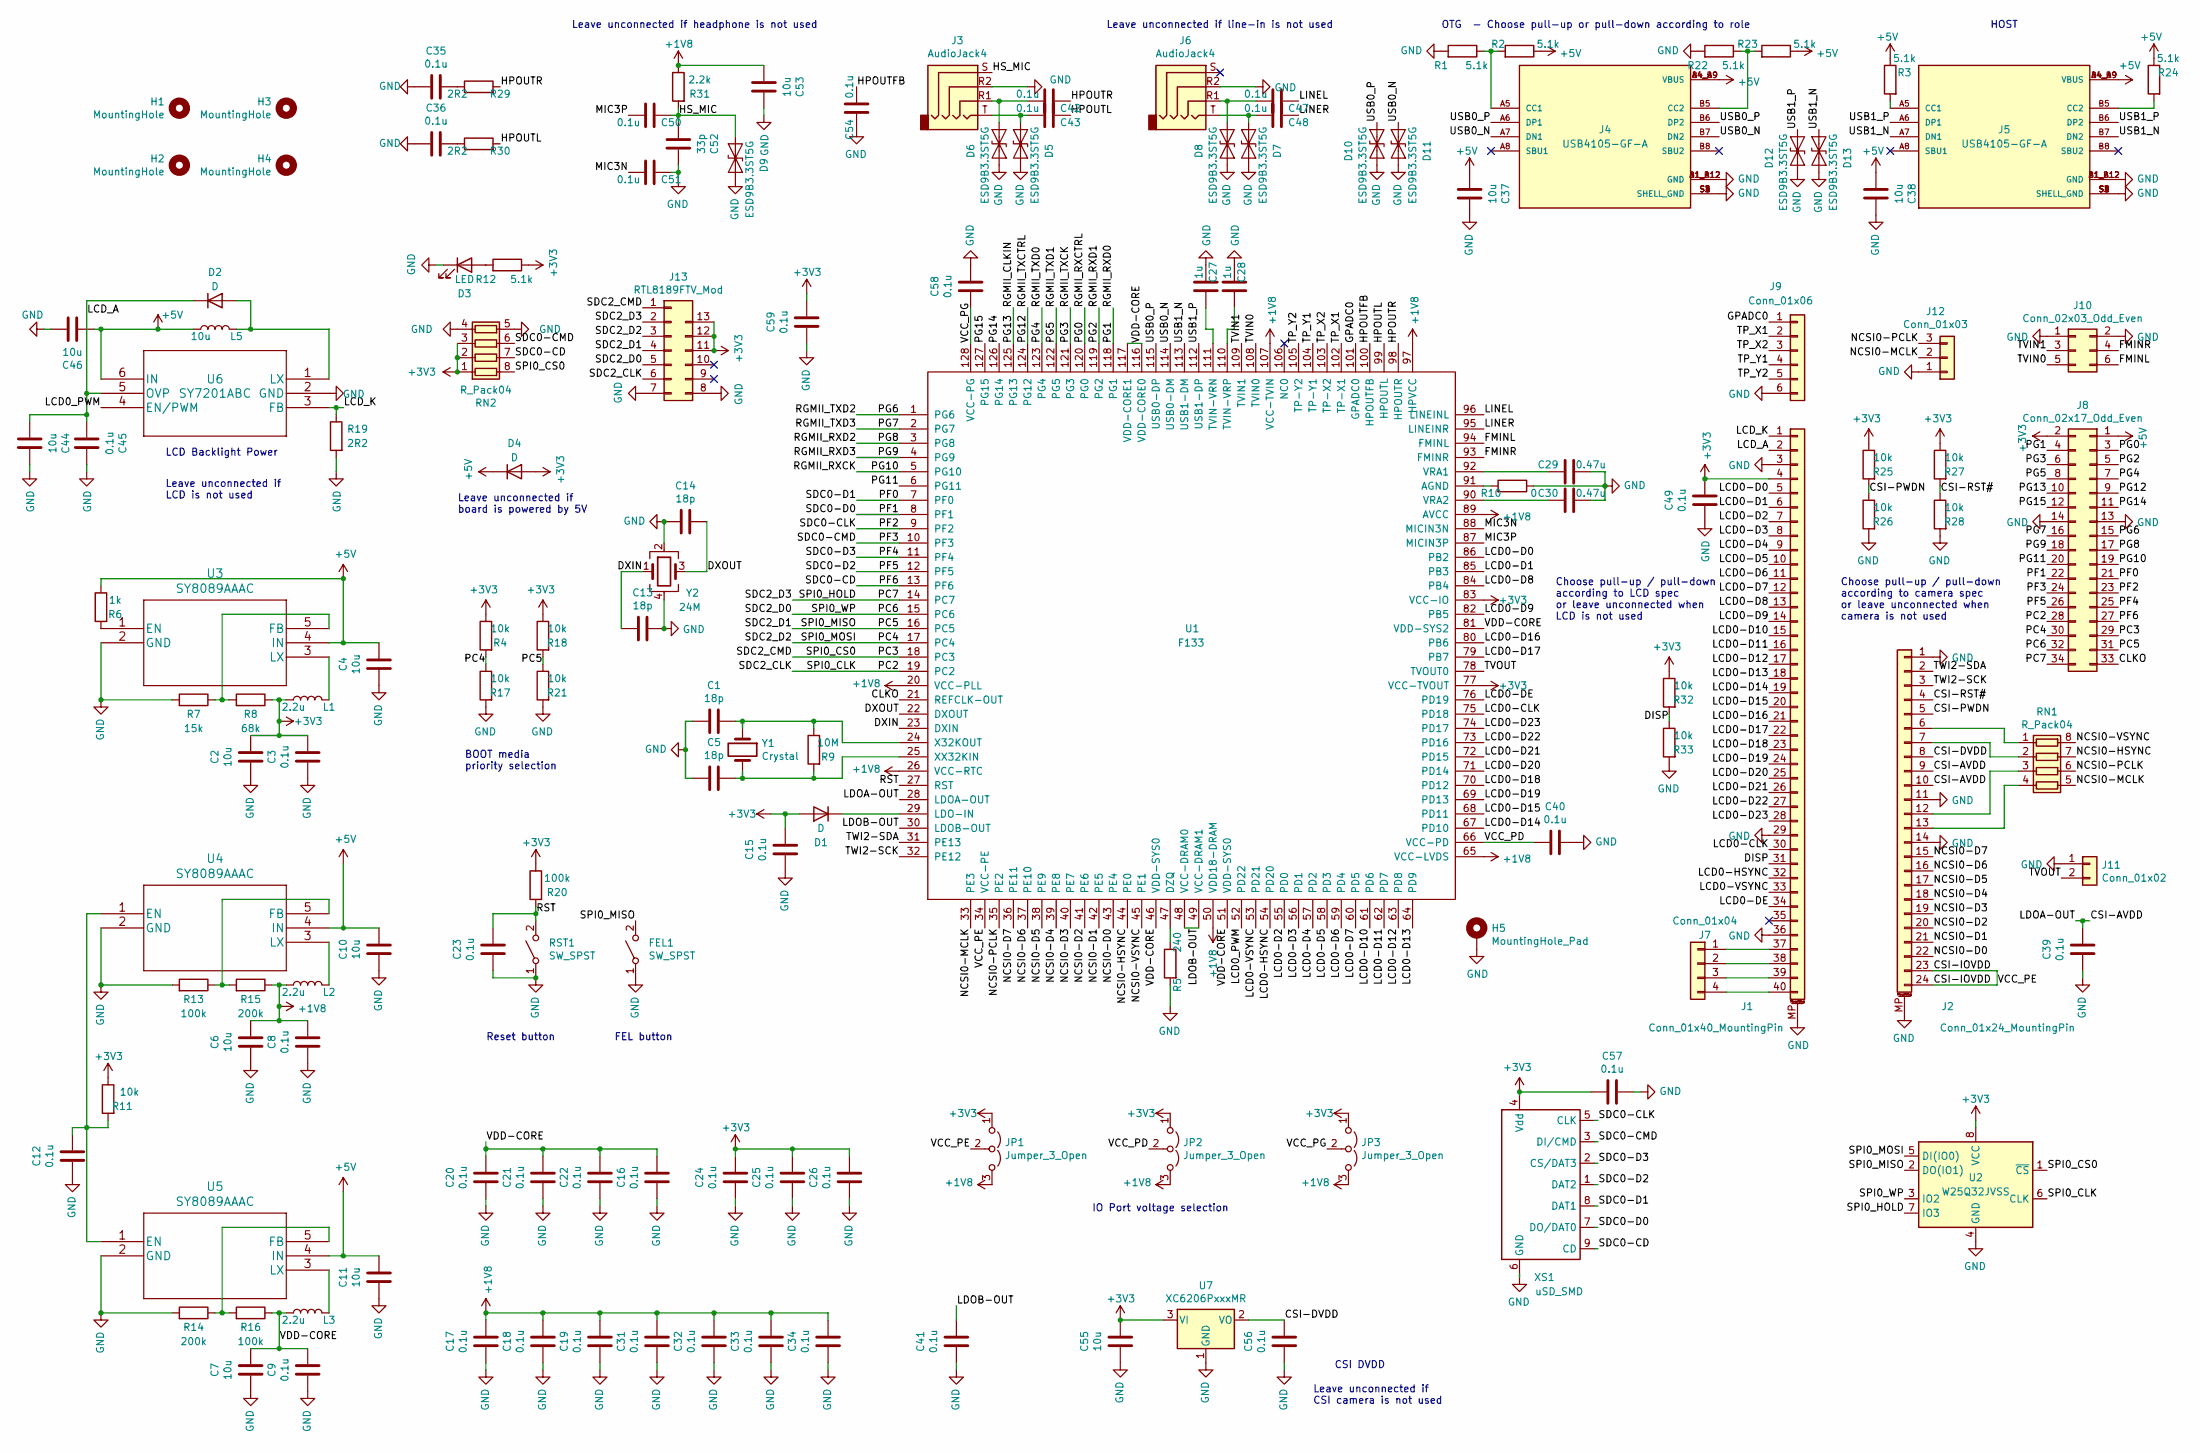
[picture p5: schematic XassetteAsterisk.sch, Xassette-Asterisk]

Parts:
C1, C5, C13, C14: 18p; C_0603_1608Metric
C2, C4, C6, C7, C10, C11, C37, C38, C44, C46, C53, C55: 10u; C_0603_1608Metric
C3, C8, C9, C12, C15, C16, C17, C18, C19, C20, C21, C22, C23, C24, C25, C26, C31, C32, C33, C34, C35, C36, C39, C40, C41, C42, C43, C45, C47, C48, C49, C50, C51, C54, C56, C57, C58, C59: 0.1u; C_0603_1608Metric
C27, C28: 1u; C_0603_1608Metric
C29, C30: 0.47u; C_0603_1608Metric
C52: 33p; C_0603_1608Metric
D1, D2, D4: D; D_SOD-323
D3: LED; LED_0603_1608Metric
D5, D6, D7, D8, D9, D10, D11, D12, D13: ESD9B3.3ST5G; D_SOD-923
FEL1: SW_SPST; SW_SPST_EVQPE1
H1, H2, H3, H4: MountingHole; MountingHole_3.2mm_M3
H5: MountingHole_Pad; SolderWirePad_1x01_SMD_5x10mm
J1: Conn_01x40_MountingPin; TE_4-1734839-0_1x40-1MP_P0.5mm_Horizontal
J2: Conn_01x24_MountingPin; TE_2-1734839-4_1x24-1MP_P0.5mm_Horizontal
J3, J6: AudioJack4; Jack_3.5mm_PJ320D_Horizontal
J4, J5: USB4105-GF-A; GCT_USB4105-GF-A; PARTREV A3
J7: Conn_01x04; PinSocket_1x04_P2.00mm_Vertical
J8: Conn_02x17_Odd_Even; PinSocket_2x17_P2.54mm_Vertical
J9: Conn_01x06; PinHeader_1x06_P2.00mm_Vertical
J10: Conn_02x03_Odd_Even; PinHeader_2x03_P2.00mm_Vertical
J11: Conn_01x02; PinHeader_1x02_P2.00mm_Vertical
J12: Conn_01x03; PinHeader_1x03_P2.54mm_Vertical
J13: RTL8189FTV_Mod; 8189Mod
JP1, JP2, JP3: Jumper_3_Open; SolderJumper-3_P2.0mm_Open_TrianglePad1.0x1.5mm
L1, L2, L3: 2.2u; L_Wuerth_MAPI-2510
L5: 10u; L_Wuerth_MAPI-2510
R1, R2, R3, R12, R22, R23, R24: 5.1k; R_0603_1608Metric
R4, R11, R17, R18, R21, R25, R26, R27, R28, R32, R33: 10k; R_0603_1608Metric
R5: 240; R_0603_1608Metric
R6: 1k; R_0603_1608Metric
R7: 15k; R_0603_1608Metric
R8: 68k; R_0603_1608Metric
R9: 10M; R_0603_1608Metric
R10: 0; R_0603_1608Metric
R13, R16, R20: 100k; R_0603_1608Metric
R14, R15: 200k; R_0603_1608Metric
R19, R29, R30: 2R2; R_0603_1608Metric
R31: 2.2k; R_0603_1608Metric
RN1, RN2: R_Pack04; R_Array_Convex_4x0603
RST1: SW_SPST; SW_SPST_EVQPE1
U1: F133; LQFP-128_14x14mm_P0.4mm
U2: W25Q32JVSS; SOIC-8_5.23x5.23mm_P1.27mm
U3, U4, U5: SY8089AAAC; SOT-23-5
U6: SY7201ABC; SOT-23-6
U7: XC6206PxxxMR; SOT-23
XS1: uSD_SMD; Conn_uSDcard
Y1: Crystal; Crystal_SMD_3215-2Pin_3.2x1.5mm
Y2: 24M; Crystal_SMD_3225-4Pin_3.2x2.5mm

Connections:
+1V8: C6.1, C8.1, C17.1, C18.1, C19.1, C31.1, C32.1, C33.1, C34.1, C53.1, JP1.3 (B), JP2.3 (B), JP3.3 (B), L2.1, R15.1, R31.1, U1.20 (VCC-PLL), U1.26 (VCC-RTC), U1.50 (VDD18-DRAM), U1.65 (VCC-LVDS), U1.89 (AVCC), U1.97 (HPVCC), U1.107 (VCC-TVIN)
+3V3: C2.1, C3.1, C15.1, C24.1, C25.1, C26.1, C49.1, C55.2, C57.1, C59.1, D1.2 (A), D4.2 (A), J1.4, J8.2, J13.11, J13.12, J13.13, JP1.1 (A), JP2.1 (A), JP3.1 (A), L1.1, R4.1, R8.1, R11.1, R12.1, R18.1, R20.1, R25.1, R27.1, R32.1, RN2.1 (R1.1), RN2.2 (R2.1), RN2.3 (R3.1), U1.77 (VCC-TVOUT), U1.83 (VCC-IO), U2.8 (VCC), U7.3 (VI), XS1.4 (Vdd)
+5V: C4.1, C10.1, C11.1, C37.1, C38.1, C46.1, D4.1 (K), J4.A4_B9 (VBUS), J4.B4_A9 (VBUS), J5.A4_B9 (VBUS), J5.B4_A9 (VBUS), J8.1, L5.1, R2.1, R3.1, R6.1, R23.1, R24.1, U3.4 (IN), U4.4 (IN), U5.4 (IN), U6.6 (IN)
/CLKO: J8.33, U1.21 (REFCLK-OUT)
/CSI-AVDD: C39.1, J2.9, J2.10, U1.28 (LDOA-OUT)
/CSI-DVDD: C56.1, J2.8, U7.2 (VO)
/CSI-IOVDD: J2.23, J2.24, JP1.2 (C), U1.34 (VCC-PE)
/CSI-PWDN: J2.5, R25.2, R26.1
/CSI-RST#: J2.4, R27.2, R28.1
/DISP: J1.31, R32.2, R33.1
/DXIN: C13.2, U1.23 (DXIN), Y2.1
/DXOUT: C14.1, U1.22 (DXOUT), Y2.3
/FMINL: J10.6, U1.94 (FMINL)
/FMINR: J10.4, U1.93 (FMINR)
/GPADC0: J9.1, U1.101 (GPADC0)
/HPOUTFB: C54.1, U1.100 (HPOUTFB)
/HPOUTL: C43.2, R30.2, U1.99 (HPOUTL)
/HPOUTR: C42.2, R29.2, U1.98 (HPOUTR)
/HS_MIC: C50.2, C52.1, D9.2 (A2), J3.S, R31.2
/LCD0-CLK: J1.30, U1.75 (PD18)
/LCD0-D0: J1.5, U1.86 (PB2)
/LCD0-D1: J1.6, U1.85 (PB3)
/LCD0-D2: J1.7, U1.55 (PD0)
/LCD0-D3: J1.8, U1.56 (PD1)
/LCD0-D4: J1.9, U1.57 (PD2)
/LCD0-D5: J1.10, U1.58 (PD3)
/LCD0-D6: J1.11, U1.59 (PD4)
/LCD0-D7: J1.12, U1.60 (PD5)
/LCD0-D8: J1.13, U1.84 (PB4)
/LCD0-D9: J1.14, U1.82 (PB5)
/LCD0-D10: J1.15, U1.61 (PD6)
/LCD0-D11: J1.16, U1.62 (PD7)
/LCD0-D12: J1.17, U1.63 (PD8)
/LCD0-D13: J1.18, U1.64 (PD9)
/LCD0-D14: J1.19, U1.67 (PD10)
/LCD0-D15: J1.20, U1.68 (PD11)
/LCD0-D16: J1.21, U1.80 (PB6)
/LCD0-D17: J1.22, U1.79 (PB7)
/LCD0-D18: J1.23, U1.70 (PD12)
/LCD0-D19: J1.24, U1.69 (PD13)
/LCD0-D20: J1.25, U1.71 (PD14)
/LCD0-D21: J1.26, U1.72 (PD15)
/LCD0-D22: J1.27, U1.73 (PD16)
/LCD0-D23: J1.28, U1.74 (PD17)
/LCD0-DE: J1.34, U1.76 (PD19)
/LCD0-HSYNC: J1.32, U1.54 (PD20)
/LCD0-VSYNC: J1.33, U1.53 (PD21)
/LCD0_PWM: U1.52 (PD22), U6.4 (EN/PWM)
/LCD_A: C44.1, C45.1, D2.1 (K), J1.2, U6.5 (OVP)
/LCD_K: J1.1, R19.1, U6.3 (FB)
/LDOB-OUT: C41.1, U1.30 (LDOB-OUT), U1.48 (VCC-DRAM0), U1.49 (VCC-DRAM1)
/LINEL: C47.2, U1.96 (LINEINL)
/LINER: C48.2, U1.95 (LINEINR)
/MIC3N: C51.1, U1.88 (MICIN3N)
/MIC3P: C50.1, U1.87 (MICIN3P)
/NCSI0-D0: J2.22, U1.43 (PE4)
/NCSI0-D1: J2.21, U1.42 (PE5)
/NCSI0-D2: J2.20, U1.41 (PE6)
/NCSI0-D3: J2.19, U1.40 (PE7)
/NCSI0-D4: J2.18, U1.39 (PE8)
/NCSI0-D5: J2.17, U1.38 (PE9)
/NCSI0-D6: J2.16, U1.37 (PE10)
/NCSI0-D7: J2.15, U1.36 (PE11)
/NCSI0-HSYNC: RN1.7 (R2.2), U1.44 (PE0)
/NCSI0-MCLK: J12.2, RN1.5 (R4.2), U1.33 (PE3)
/NCSI0-PCLK: J12.3, RN1.6 (R3.2), U1.35 (PE2)
/NCSI0-VSYNC: RN1.8 (R1.2), U1.45 (PE1)
/PC2: J8.28, J13.6, U1.19 (PC2), U2.6 (CLK)
/PC3: J8.29, J13.1, RN2.8 (R1.2), U1.18 (PC3), U2.1 (~CS)
/PC4: J8.30, J13.3, R4.2, R17.1, U1.17 (PC4), U2.5 (DI(IO0))
/PC5: FEL1.2 (B), J8.31, J13.4, R18.2, R21.1, U1.16 (PC5), U2.2 (DO(IO1))
/PC6: J8.32, J13.5, U1.15 (PC6), U2.3 (IO2)
/PC7: J8.34, J13.2, U1.14 (PC7), U2.7 (IO3)
/PF0: J8.21, U1.7 (PF0), XS1.8 (DAT1)
/PF1: J8.22, U1.8 (PF1), XS1.7 (DO/DAT0)
/PF2: J8.23, U1.9 (PF2), XS1.5 (CLK)
/PF3: J8.24, RN2.6 (R3.2), U1.10 (PF3), XS1.3 (DI/CMD)
/PF4: J8.25, U1.11 (PF4), XS1.2 (CS/DAT3)
/PF5: J8.26, U1.12 (PF5), XS1.1 (DAT2)
/PF6: J8.27, RN2.7 (R2.2), U1.13 (PF6), XS1.9 (CD)
/PG0: J8.3, U1.120 (PG0)
/PG1: J8.4, U1.118 (PG1)
/PG2: J8.5, U1.119 (PG2)
/PG3: J8.6, U1.121 (PG3)
/PG4: J8.7, U1.123 (PG4)
/PG5: J8.8, U1.122 (PG5)
/PG6: J8.15, U1.1 (PG6)
/PG7: J8.16, U1.2 (PG7)
/PG8: J8.17, U1.3 (PG8)
/PG9: J8.18, U1.4 (PG9)
/PG10: J8.19, U1.5 (PG10)
/PG11: J8.20, U1.6 (PG11)
/PG12: J8.9, U1.124 (PG12)
/PG13: J8.10, U1.125 (PG13)
/PG14: J8.11, U1.126 (PG14)
/PG15: J8.12, U1.127 (PG15)
/RST: C23.1, R20.2, RST1.2 (B), U1.27 (RST)
/TP_X1: J9.2, U1.102 (TP-X1)
/TP_X2: J9.3, U1.103 (TP-X2)
/TP_Y1: J9.4, U1.104 (TP-Y1)
/TP_Y2: J9.5, U1.105 (TP-Y2)
/TVIN0: J10.5, U1.108 (TVIN0)
/TVIN1: J10.3, U1.109 (TVIN1)
/TVOUT: J11.2, U1.78 (TVOUT0)
/TWI2-SCK: J2.3, U1.32 (PE12)
/TWI2-SDA: J2.2, U1.31 (PE13)
/USB0_N: D11.2 (A2), J4.A7 (DN1), J4.B7 (DN2), U1.114 (USB0-DM)
/USB0_P: D10.2 (A2), J4.A6 (DP1), J4.B6 (DP2), U1.115 (USB0-DP)
/USB1_N: D13.2 (A2), J5.A7 (DN1), J5.B7 (DN2), U1.113 (USB1-DM)
/USB1_P: D12.2 (A2), J5.A6 (DP1), J5.B6 (DP2), U1.112 (USB1-DP)
/VCC_PD: C40.2, JP2.2 (C), U1.66 (VCC-PD)
/VCC_PG: C58.2, JP3.2 (C), U1.128 (VCC-PG)
/VDD-CORE: C7.1, C9.1, C16.1, C20.1, C21.1, C22.1, L3.1, R16.1, U1.46 (VDD-SYS0), U1.51 (VDD-SYS0), U1.81 (VDD-SYS2), U1.116 (VDD-CORE0), U1.117 (VDD-CORE1)
GND: C1.2, C2.2, C3.2, C4.2, C5.2, C6.2, C7.2, C8.2, C9.2, C10.2, C11.2, C12.2, C13.1, C14.2, C15.2, C16.2, C17.2, C18.2, C19.2, C20.2, C21.2, C22.2, C23.2, C24.2, C25.2, C26.2, C27.2, C28.2, C29.1, C30.1, C31.2, C32.2, C33.2, C34.2, C35.1, C36.1, C37.2, C38.2, C39.2, C40.1, C41.2, C44.2, C45.2, C46.2, C49.2, C51.2, C52.2, C53.2, C54.2, C55.1, C56.2, C57.2, C58.1, C59.2, D3.1 (K), D5.1 (A1), D6.1 (A1), D7.1 (A1), D8.1 (A1), D9.1 (A1), D10.1 (A1), D11.1 (A1), D12.1 (A1), D13.1 (A1), FEL1.1 (A), H5.1, J1.3, J1.29, J1.36, J1.MP (MountPin), J2.1, J2.11, J2.14, J2.MP (MountPin), J3.R2, J4.A1_B12 (GND), J4.B1_A12 (GND), J4.S1 (SHELL_GND), J4.S2 (SHELL_GND), J4.S3 (SHELL_GND), J4.S4 (SHELL_GND), J5.A1_B12 (GND), J5.B1_A12 (GND), J5.S1 (SHELL_GND), J5.S2 (SHELL_GND), J5.S3 (SHELL_GND), J5.S4 (SHELL_GND), J6.R2, J8.13, J8.14, J9.6, J10.1, J10.2, J11.1, J12.1, J13.7, J13.8, R1.2, R5.2, R7.2, R10.1, R13.2, R14.2, R17.2, R19.2, R21.2, R22.2, R26.2, R28.2, R33.2, RN2.4 (R4.1), RN2.5 (R4.2), RST1.1 (A), U2.4 (GND), U3.2 (GND), U4.2 (GND), U5.2 (GND), U6.2 (GND), U7.1 (GND), XS1.6 (GND), Y2.2, Y2.4
unnamed: C1.1, R9.1, U1.24 (X32KOUT), Y1.1
unnamed: C5.1, R9.2, U1.25 (XX32KIN), Y1.2
unnamed: C12.1, R11.2, U4.1 (EN), U5.1 (EN)
unnamed: C27.1, U1.111 (TVIN-VRN)
unnamed: C28.1, U1.110 (TVIN-VRP)
unnamed: C29.2, U1.92 (VRA1)
unnamed: C30.2, U1.90 (VRA2)
unnamed: C35.2, R29.1
unnamed: C36.2, R30.1
unnamed: C42.1, D6.2 (A2), J3.R1
unnamed: C43.1, D5.2 (A2), J3.T
unnamed: C47.1, D8.2 (A2), J6.R1
unnamed: C48.1, D7.2 (A2), J6.T
unnamed: D1.1 (K), U1.29 (LDO-IN)
unnamed: D2.2 (A), L5.2, U6.1 (LX)
unnamed: D3.2 (A), R12.2
unnamed: J1.37, J7.1
unnamed: J1.38, J7.2
unnamed: J1.39, J7.3
unnamed: J1.40, J7.4
unnamed: J2.6, RN1.1 (R1.1)
unnamed: J2.7, RN1.2 (R2.1)
unnamed: J2.12, RN1.3 (R3.1)
unnamed: J2.13, RN1.4 (R4.1)
unnamed: J4.A5 (CC1), R1.1, R2.2
unnamed: J4.B5 (CC2), R22.1, R23.2
unnamed: J5.A5 (CC1), R3.2
unnamed: J5.B5 (CC2), R24.2
unnamed: L1.2, U3.3 (LX)
unnamed: L2.2, U4.3 (LX)
unnamed: L3.2, U5.3 (LX)
unnamed: R5.1, U1.47 (DZQ)
unnamed: R6.2, U3.1 (EN)
unnamed: R7.1, R8.2, U3.5 (FB)
unnamed: R10.2, U1.91 (AGND)
unnamed: R13.1, R15.2, U4.5 (FB)
unnamed: R14.1, R16.2, U5.5 (FB)

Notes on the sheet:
Leave unconnected if board is powered by 5V
Leave unconnected if LCD is not used
LCD Backlight Power
BOOT media priority selection
IO Port voltage selection
Leave unconnected if CSI camera is not used
CSI DVDD
Choose pull-up / pull-down according to camera spec or leave unconnected when camera is not used
Choose pull-up / pull-down according to LCD spec or leave unconnected when LCD is not used
Leave unconnected if headphone is not used
Leave unconnected if line-in is not used
OTG - Choose pull-up or pull-down according to role
Reset button
HOST
FEL button

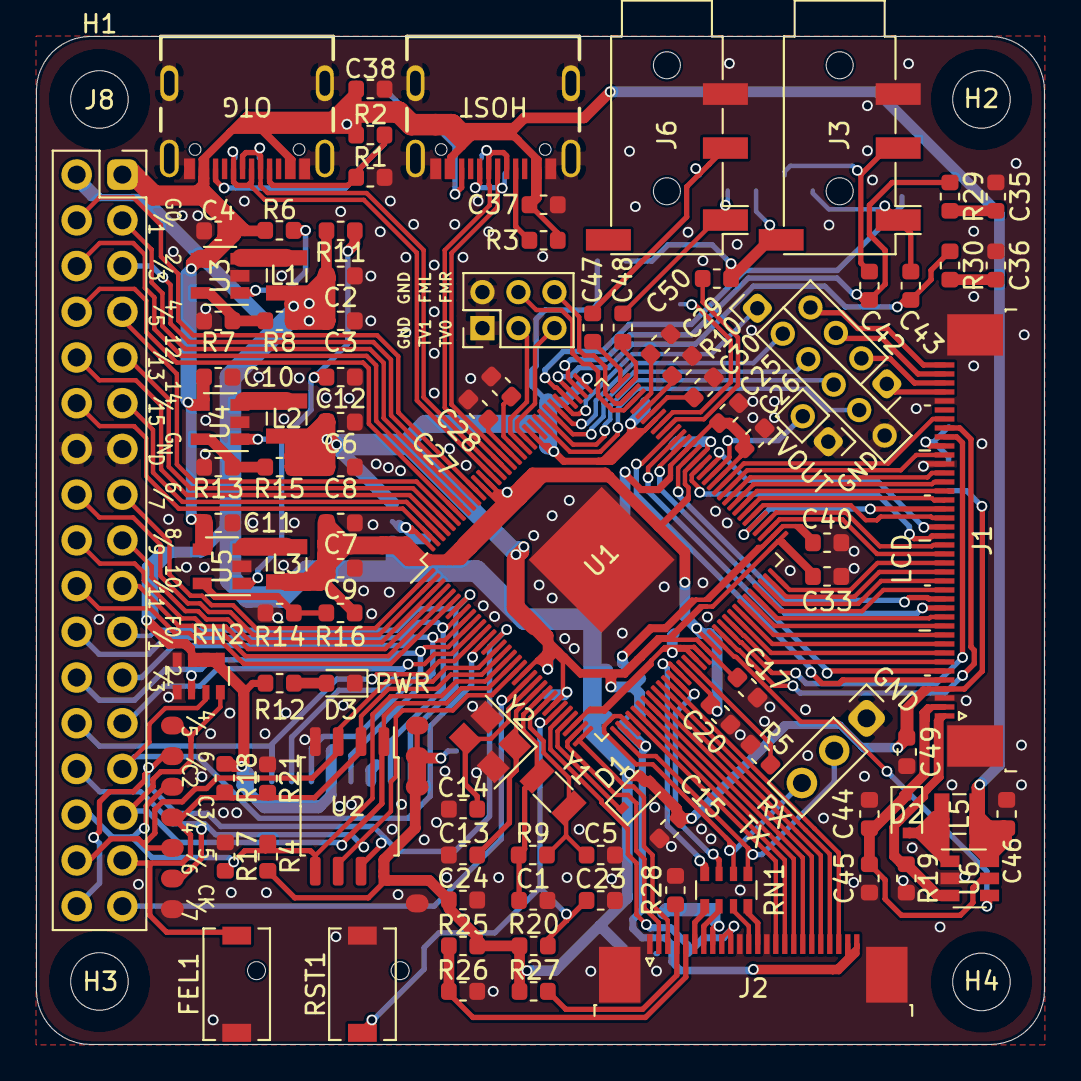
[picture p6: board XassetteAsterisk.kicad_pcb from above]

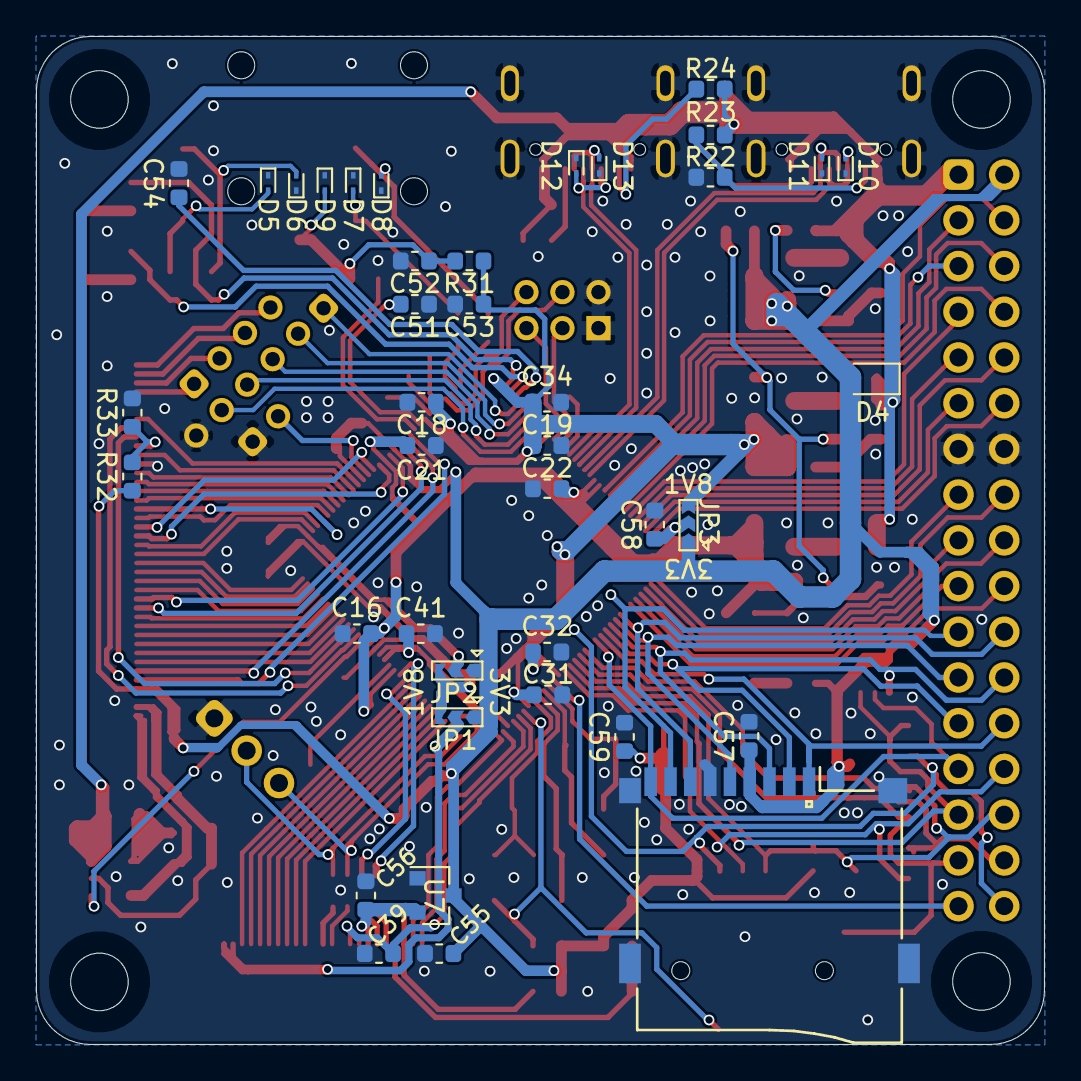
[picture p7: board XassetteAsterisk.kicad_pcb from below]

Board: 2 copper layers, 56.0 x 56.0 mm, 145 parts (41 on the bottom side), 151 nets.

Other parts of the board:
Ref**: Val**; rvlogo_inv

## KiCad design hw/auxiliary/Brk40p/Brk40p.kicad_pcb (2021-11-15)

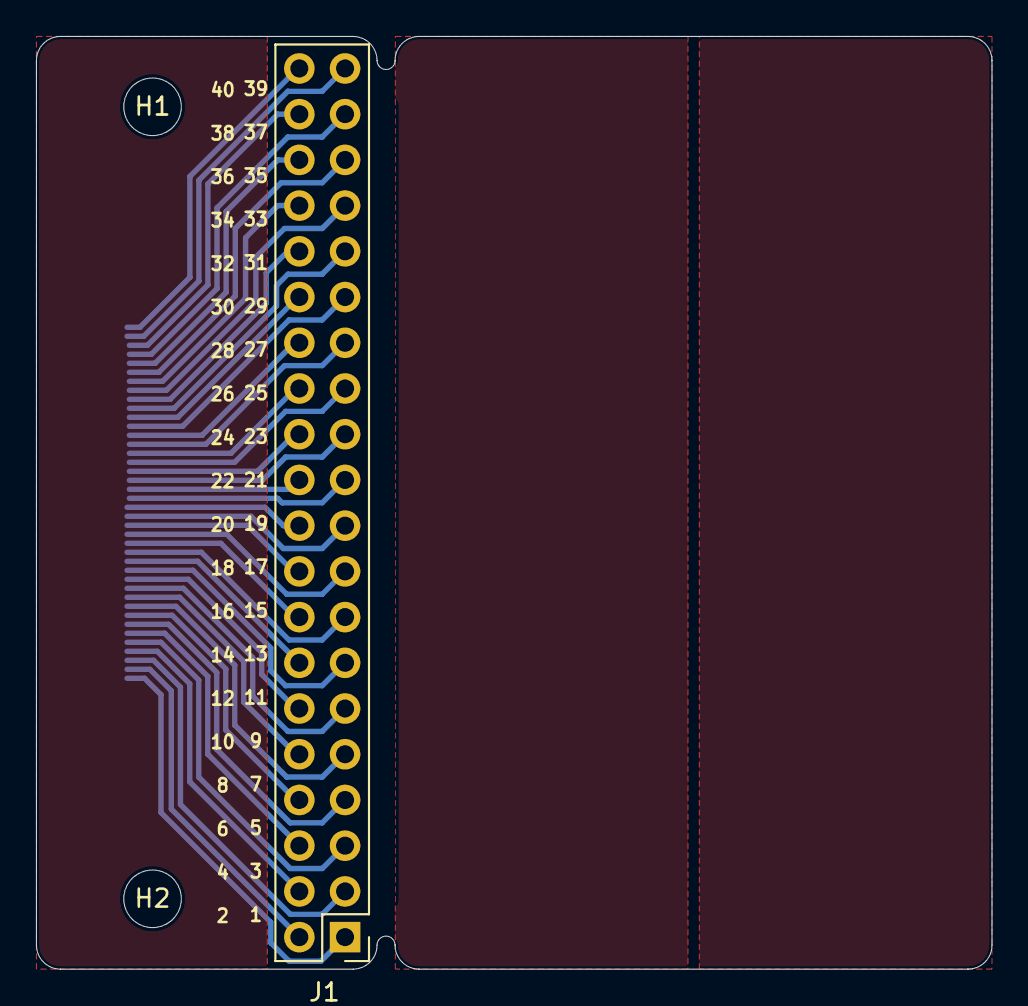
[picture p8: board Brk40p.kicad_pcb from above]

Board: 2 copper layers, 53.1 x 51.8 mm, 4 parts (1 on the bottom side), 40 nets.

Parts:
H1, H2: MountingHole; MountingHole_3.2mm_M3
J1: Conn_01x40; PinHeader_2x20_P2.54mm_Vertical
J2: Conn_01x40_MountingPin; TE_4-1734839-0_1x40-1MP_P0.5mm_Horizontal

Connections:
unnamed: J1.1, J2.1
unnamed: J1.2, J2.2
unnamed: J1.3, J2.3
unnamed: J1.4, J2.4
unnamed: J1.5, J2.5
unnamed: J1.6, J2.6
unnamed: J1.7, J2.7
unnamed: J1.8, J2.8
unnamed: J1.9, J2.9
unnamed: J1.10, J2.10
unnamed: J1.11, J2.11
unnamed: J1.12, J2.12
unnamed: J1.13, J2.13
unnamed: J1.14, J2.14
unnamed: J1.15, J2.15
unnamed: J1.16, J2.16
unnamed: J1.17, J2.17
unnamed: J1.18, J2.18
unnamed: J1.19, J2.19
unnamed: J1.20, J2.20
unnamed: J1.21, J2.21
unnamed: J1.22, J2.22
unnamed: J1.23, J2.23
unnamed: J1.24, J2.24
unnamed: J1.25, J2.25
unnamed: J1.26, J2.26
unnamed: J1.27, J2.27
unnamed: J1.28, J2.28
unnamed: J1.29, J2.29
unnamed: J1.30, J2.30
unnamed: J1.31, J2.31
unnamed: J1.32, J2.32
unnamed: J1.33, J2.33
unnamed: J1.34, J2.34
unnamed: J1.35, J2.35
unnamed: J1.36, J2.36
unnamed: J1.37, J2.37
unnamed: J1.38, J2.38
unnamed: J1.39, J2.39
unnamed: J1.40, J2.40

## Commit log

2021-10-27 schematic revision
    [XassetteAsterisk.sch]
2021-10-29 update README with schematic
2021-11-05 add BOM list
    [BOM.csv]
2021-11-07 minor changes in schematic
    [XassetteAsterisk.sch]
2021-11-15 add expansion board
    [Brk40p.kicad_pcb, Brk40p.sch]
2021-11-25 add guides
    [BOM.csv]
2021-12-09 hw upgrade to v0.2
    [XassetteAsterisk.kicad_pcb, XassetteAsterisk.sch]
2021-12-13 hw upgrade to v0.3
    [XassetteAsterisk.kicad_pcb, XassetteAsterisk.sch]
